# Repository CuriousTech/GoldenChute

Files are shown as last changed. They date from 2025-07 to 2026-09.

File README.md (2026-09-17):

# GoldenChute
GoldenMate UPS monitor and Windows shutdown software  
  
This is a simple modification for the GoldeMate UPS to access the information displayed as well as safely shut a Windows PC down before the battery runs down. One of the most important features of a UPS.  
  
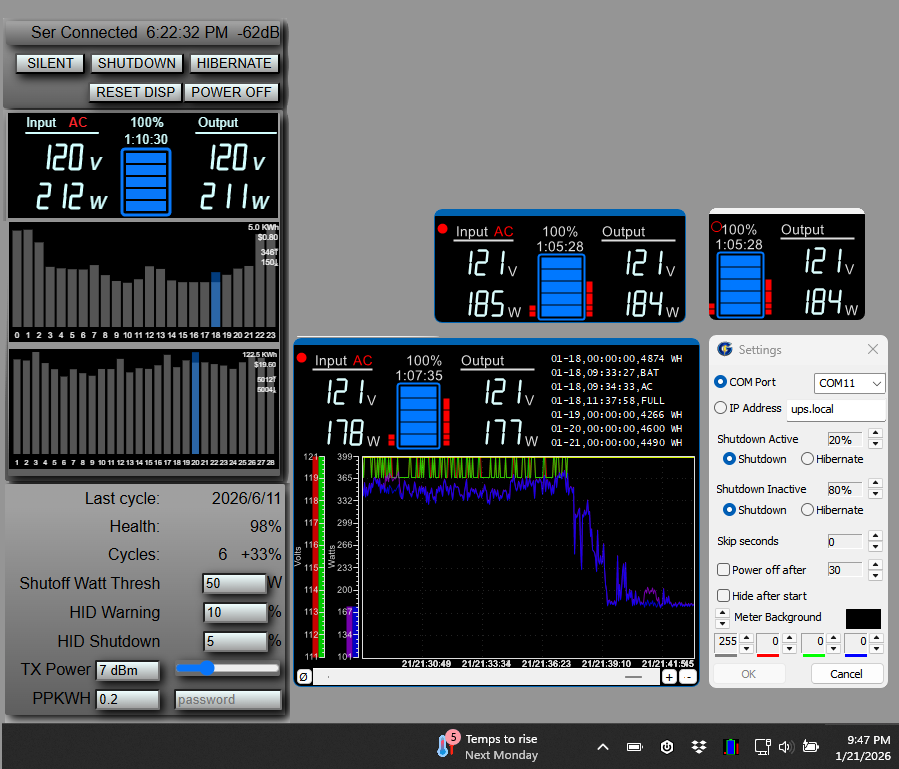
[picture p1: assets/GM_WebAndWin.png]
WebAndWinPic
  
  
The left is the web page for remote access. The other windows are the Windows app (different sizes).  
  
This mod requires opening the case of the UPS and plugging in a small board inline with the front display. It's a segmented display with SPI interface, so the ESP32 decodes all the segment bits and translates them to something usable. The data is only sent to the display for 60 seconds when the power button is short-pressed, so this also simulates the button (in parallel). The 5V power for the ESP32 needs to be external since the display 5V is only on when the display is powered, and may not support the current requirement, so run a USB cable to the rear panel and cut a small notch so the case can slide back on, and connect to PC or USB power supply (powered by the UPS, so it's powered on battery).  

Note: The interface could easily be changed to any small Arduino or microcontroller, since it only connects to 3 pins for data (no ground) and momentarily shorts the power button (28V or 56V pulled low).  
  
I beleve the first model had a push-on/push-off button and the display stayed on. For that model, all you need is the PCB, ESP32, and 7 pin connectors. Leave out the solid state relay, R2 and 2 pin connectors.  
  
**Parts needed:**  
-  [PCB r4](https://oshpark.com/shared_projects/ARcXjJj3)  Moved the DI trace to fix RF issues with a new module, and removed ground fill around it as well.  
-  [ESP32-C3-super mini](https://www.aliexpress.us/item/3256807353297685.html), or [ESP32-S3-super mini](https://www.aliexpress.us/item/3256809251035142.html) for USB-HID support (native Windows, NUT, etc.)  
-  AQY282S (SSR)  I used this one because it's cheap and currently well stocked.  
-  R1 470 ohm 0805 resistor  
-  M & F [JST-XH](https://www.aliexpress.us/item/3256807274583113.html) (This one has wires to place it closer to the side for better signal) 7P 2.54mm, or 7P 0.1" pinheader  
-  2P 2.54mm/0.1" connector M  
-  2P 2.54mm/0.1" connector F + 2 wires (3-4 inches) Note: The button is non-polarized (The AliExpress above didn't fit the 2 pin) Dupont will work if nothing else.  
-  1x 18650 cell and [holder](https://www.aliexpress.us/item/3256808726723157.html) for battery power on the ESP32. Solder the wires on the back of the ESP32 first.  
-  r5 board: 3x BSS138 (MOSFET), 3x 10K resistors, and another AQY282S + 470 resistor. This is still an untested board. The addition of the SSR is because the front button is DPST. One side is for the BMS (display control). The other side is for the UPS (powering on/off and beeper mute). Some models have separate buttons for this function, and may have different input timings.  
  
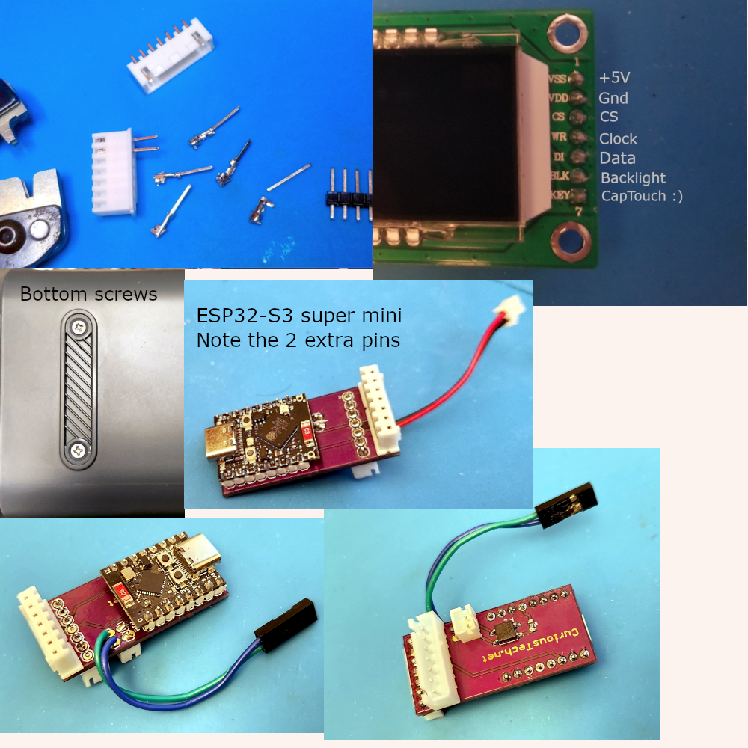
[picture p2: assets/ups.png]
UPS Board
  
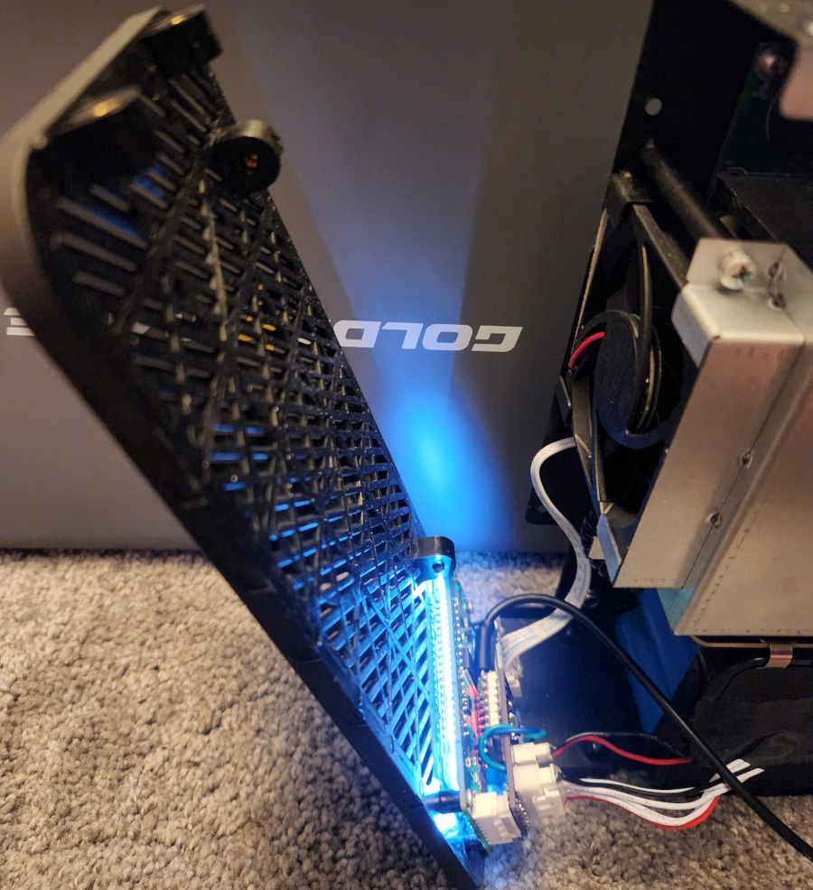
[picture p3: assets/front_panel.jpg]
Front panel
  
  
Remove the 2 screws under each rubber foot. Slide the cover off (to the front).  Remove the 6 screws around the front panel.  
  
The female XHB (XH works well, and a plain female pinheader actually holds well if you can't find XH/B) connector needs pins or wire lead clippings crimped to make it solder to a PCB. I used male pinheader pins. Install the 2-pin connector and wires before the ESP32 for ease.  
  
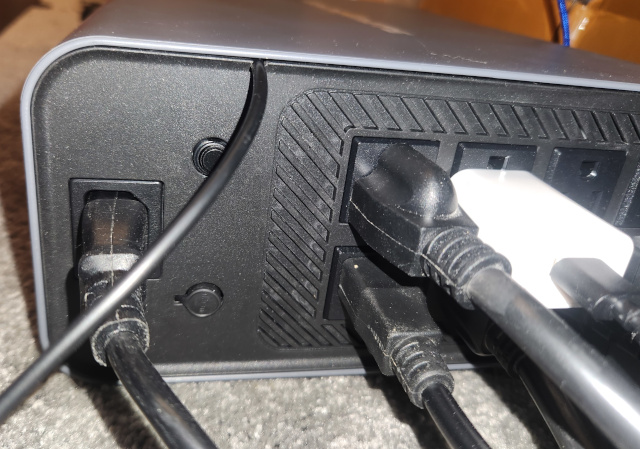
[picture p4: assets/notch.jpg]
Back
  
Cut a notch in the rear panel to fit the USB cable.  
  
**Arduino:**  
Settings for router SSID and SSID password are in Config.h, as well as the remote password for web control. If they aren't set or the SSID changes, EspTouch can be used.  
Compiling the code should be easy. Most information is in UPS.ino, like where to get the libraries needed, and settings for the ESP32-C3-super mini such as enabling CDC on boot (for serial output).  
There's code in UPS.ino to setup the initialDate, lastCycleDate, Cycles and percent to be used once, and commented out if desired.  

The ESP32-S3 super mini is mostly pin compatible, and has HID support for UPS emulation. It has 2 more pins (1 per side) that just overhang on the PCB. The current GPIO pins in the code for the C3 are incorrect for the r3 board. Just 1 pin is different. There are likely different models of the S3 also. Just make sure GND is pin 2.  
  
**Web page:**  
The HIBERNATE and SHUTDOWN buttons send a message to the Goldenmate app to start the shutdown or hibernate process.  
The POWER OFF button will hold the power button for 5 seconds to shut the UPS off. This will cut power to everything, including the ESP32 most likely.  
RESET DISP causes a timeout in the display restart timer. When the USP returns to AC power, once in a while the display malfunctions, but the data is still good. This just fixes it.  
BEEPING / SILENT toggles to enable a button tap at the start of backup power, disabling the beeps.  
Shutoff Watt Threshold prevents the delayed shutoff from operating until the watts out drops below the set value.  
HID Warn % is what Windows uses to pop up a warning.  
HID shutdown % is what Windows uses to shutdown when the battery level reaches that value. Set the warning above the shutdown. These are overridden by settings in Windows, though, so probably not useful.  
PPKWH (price per killowatt hour) is used for, well, calcuating cost.  
password needs to be the same as what's in Config.h and needs to be set to allow any input (button presses or value changes). You can leave it blank any other time.  
  
**Windows app:**  
Extract the exe and move it to somewhere like C:\Goldenmate.  The startup folder symbolic link will auto-generate to this path.  
Clicking on the top-right corner of the app will hide it.  
Right-click for context menu (settings, quit, clear log/chart)  
The outage and daily WH log (top right area, hidden when small) is blank until an entry is created.  Entries are comma delimited lines saved in a file in the local exe folder, named ups_log.txt (or ups_log1.txt for the 2nd instance...).  
  
**Settings:**  
Right-click in the window, or go to the tray, and right click the icon for the menu. Select "Settings" and enter the IP address of the ESP32 device in the format "192.168.xxx.xxx" which you can find in the Arduino IDE ports, named UPS (192.168.xxx.xxx). Up to 8 clients can be connected at once. Your router should also be on UPS when using this method.  
If it connects, there should be a small red circle in the top left of the app. This will blink when data is received. Serial is the same.  
COM Port (Note: using serial will cause the ESP32 to reset every time the app exits or another app accesses the COM port, which loses WH history and may get off track if charging).  
The radio buttons allow selecting either COM or websocket.  
 Note: When using HID, the Windows app will not be able to use serial, but can connect to the IP address. There's no resetting, which is better, but be careful of the HID shutdown % along with the app shutdown %. The app should be set higher, and HID can be fallback if it's not running for any reason.  
Percent to shut down: Active (red bars left of battery in the main display and tray icon) and Inactive (right red bars) depends on whether the monitor is in standby. The depth of discharge (D.O.D.) determines the impact on health. When inactive, it should shut down at 70% for best health. When active, more time can be allowed for manual shutdown. The % is just the bar levels, not actual percent (which could possibly be inaccurate). There is a 10 second delay when it reaches the desired %, then it will shut down or hibernate/hibrid-sleep if that is set up properly and doesn't fail, otherwise it will shut down.  
Note: Hibrid-sleep can wake immediately by odd USB devices if not set up properly. It should be tested before use. It will also slowly drain the battery over time.  
Skip seconds: 0 will add data to the chart every second (total 24 hours). 1 would be 48 hours, but records peak values of 2 seconds.  
Alerts cause the window to popup and show a text box such as "Serial timeout/in use" or WebSocket disconnected" with annoying sound.  
Power off after [30] seconds: Will turn the UPS power off (cutting power to everything on it) the delayed time (15 secs to 60 mins) after the PC begins shutdown/hibernate, and also waits for the watts out to drop below the shutoff watt threshold setting on the webpage.  
 Note:The ESP will also lose power, so there's no way to remotely power it back on.  
Hide after start causes the window to hide 4 seconds after startup.

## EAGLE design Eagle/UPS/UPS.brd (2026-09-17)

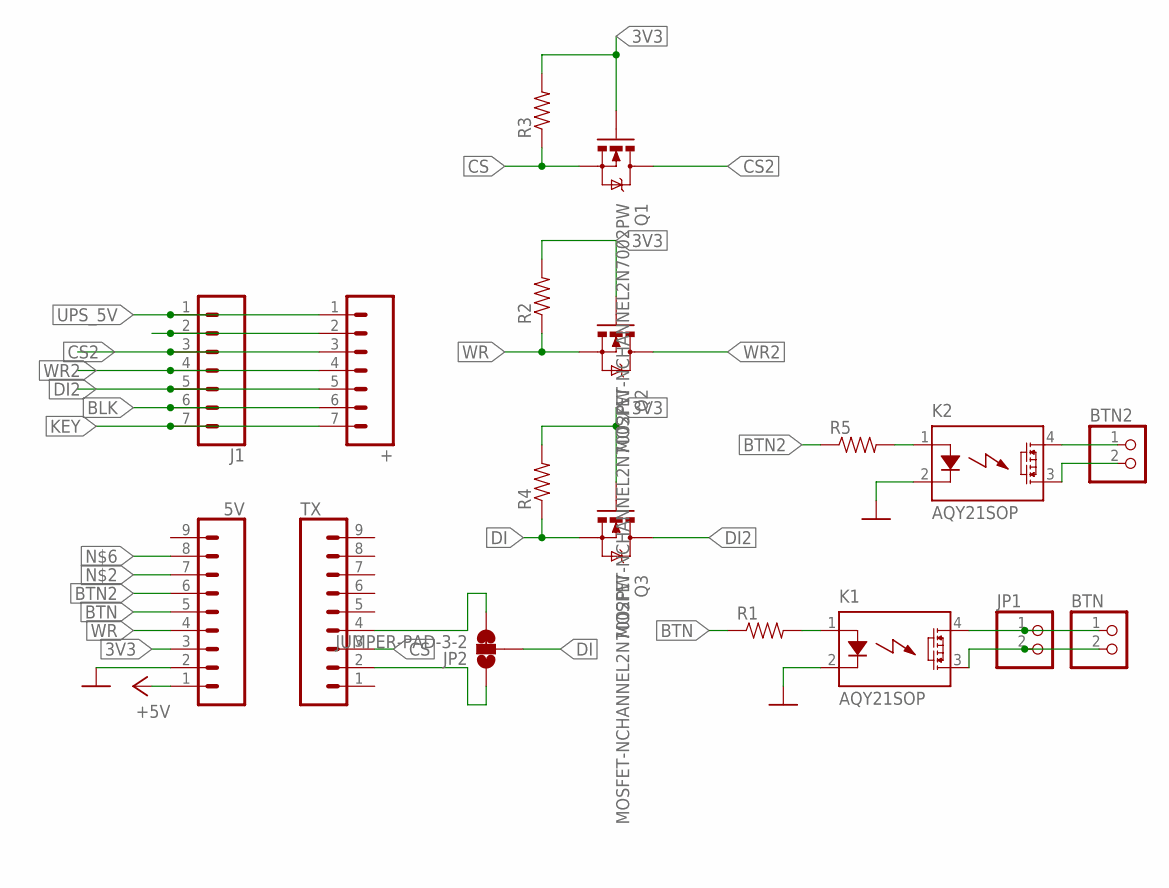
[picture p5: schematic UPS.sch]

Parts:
5V: CONN_09; 1X09
+: CONN_07; 1X07
BTN, BTN2: PINHD-1X2; 1X02
J1: CONN_07; 1X07
JP1: PINHD-1X2; 1X02
JP2: JUMPER-PAD-3-2; PAD-JUMPER-3-2OF3_NC_BY_TRACE_YES_SILK_FULL_BOX
K1, K2: AQY21SOP; SOP04
Q1, Q2, Q3: MOSFET-NCHANNEL2N7002PW; SOT323
R1, R2, R3, R4, R5: RESISTOR0805-RES; 0805
TX: CONN_09; 1X09

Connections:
3V3: 5V.3, Q1.1 (G), Q2.1 (G), Q3.1 (G), R2.2, R3.2, R4.2
+5V: 5V.1
BLK: +.6, J1.6
BTN: 5V.5, R1.1
BTN2: 5V.6, R5.1
CS: Q1.2 (S), R3.1, TX.3
CS2: +.3, J1.3, Q1.3 (D)
DI: JP2.2, Q3.2 (S), R4.1
DI2: +.5, J1.5, Q3.3 (D)
GND: 5V.2, K1.2 (K), K2.2 (K)
KEY: +.7, J1.7
unnamed: BTN.1, JP1.1, K1.4 (DS1)
unnamed: BTN.2, JP1.2, K1.3 (DS2)
unnamed: K1.1 (A), R1.2
unnamed: JP2.3, TX.4
unnamed: JP2.1, TX.2
unnamed: BTN2.1, K2.4 (DS1)
unnamed: BTN2.2, K2.3 (DS2)
unnamed: K2.1 (A), R5.2
UPSGND: +.2, J1.2
UPS_5V: +.1, J1.1
WR: 5V.4, Q2.2 (S), R2.1
WR2: +.4, J1.4, Q2.3 (D)

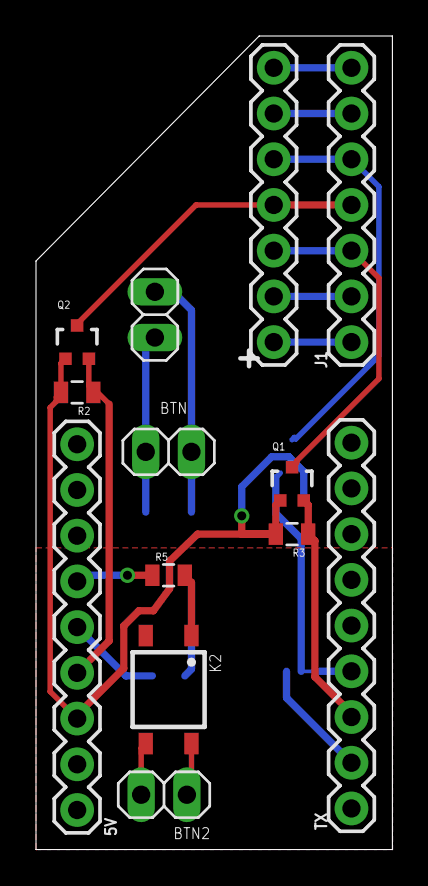
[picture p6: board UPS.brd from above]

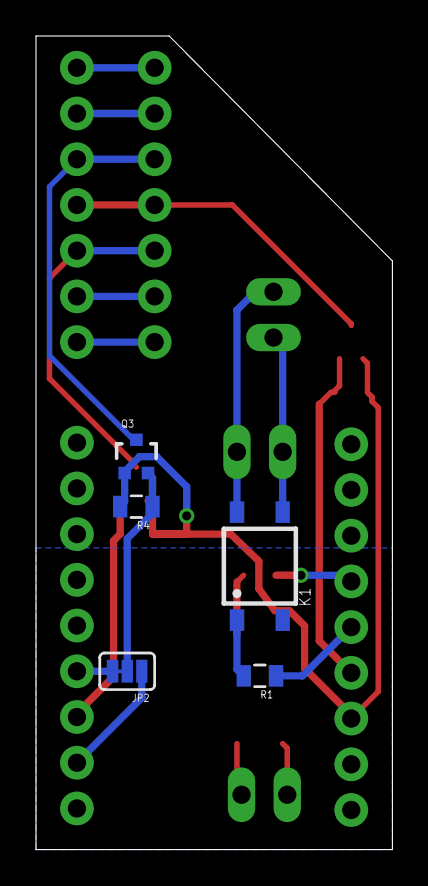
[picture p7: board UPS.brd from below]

Board: 2 copper layers, 19.8 x 45.2 mm, 18 parts (5 on the bottom side), 22 nets.

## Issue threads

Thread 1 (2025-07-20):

Connection issues

AlecMcCutcheon, 2025-07-20:
Plugged in the UPS over USB but not seeing an COM ports in the GUI and no data showing in the GUI

Any luck on the NUT driver.

CuriousTech, 2025-07-25:
The USB port will be the same as what you see in the Arduino IDE when programming the ESP-32-C3.

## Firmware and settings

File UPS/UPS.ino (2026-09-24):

/**The MIT License (MIT)

Copyright (c) 2025 by Greg Cunningham, CuriousTech

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
THE SOFTWARE IS PROVIDED "AS IS", WITHOUT WARRANTY OF ANY KIND, EXPRESS OR
IMPLIED, INCLUDING BUT NOT LIMITED TO THE WARRANTIES OF MERCHANTABILITY,
FITNESS FOR A PARTICULAR PURPOSE AND NONINFRINGEMENT. IN NO EVENT SHALL THE
AUTHORS OR COPYRIGHT HOLDERS BE LIABLE FOR ANY CLAIM, DAMAGES OR OTHER
LIABILITY, WHETHER IN AN ACTION OF CONTRACT, TORT OR OTHERWISE, ARISING FROM,
OUT OF OR IN CONNECTION WITH THE SOFTWARE OR THE USE OR OTHER DEALINGS IN THE
SOFTWARE.
*/

// Goldenmate UPS with ESP32-C3-super mini or ESP32-S3-super mini

// Build with Arduino IDE 1.8.19, ESP32 2.0.14 or 3.2.0-3.3.7
// CPU Speed: 80MHz(C3) 80MHz(S3) (Warning: These both seem to burn up at the highest clock speed)
// USB CDC On Boot: Enabled - for serial output over USB, HID doesn't matter
// Partition: Default 4MB with spiffs

///////////////////////////////////////////////////
//  Model       Volts Amps    Wh      ~98% integer
// 1000VA/600W  25.6V 6Ah   = 153.6Wh 150
// 1000VA/800W  25.6V 9Ah   = 230.4Wh 226
// 1500VA/1000W 51.2V 5.8Ah= 296Wh    291 (note: 1500 & 2000 models have a USB-HID type output AFAIK)
// 1500VA/1200W 51.2V 6Ah  = 307Wh    301   (manual is incorrect, so I'm guessing)
// 2000VA/1600W 51.2V 9Ah  = 460.8Wh  451
#define BATTERY_WH 226

#define TZ  "EST5EDT,M3.2.0,M11.1.0"  // https://github.com/nayarsystems/posix_tz_db/blob/master/zones.csv

#include <WiFi.h>
#include <ESPAsyncWebServer.h> // https://github.com/ESP32Async/ESPAsyncWebServer (3.10.1) and AsyncTCP (3.4.10)
#include <time.h>
#include <JsonParse.h> //https://github.com/CuriousTech/ESP-HVAC/tree/master/Libraries/JsonParse
#include <ArduinoOTA.h>
#include <ESPmDNS.h>
#include "Config.h"
#include "pages.h"
#include "jsonstring.h"

// ESP32-C3 on r2 PCB
#if CONFIG_IDF_TARGET_ESP32C3
#define CS_PIN  GPIO_NUM_7
#define DIN_PIN GPIO_NUM_6 // GPIO_NUM_8 // PCB r3
#define SCK_PIN GPIO_NUM_4
#define LED     8
#define BMS_BTN 3
#define UPS_BTN 2
// ESP32-S3 on r3 PCB
#elif CONFIG_IDF_TARGET_ESP32S3
#define CS_PIN  GPIO_NUM_1
#define DIN_PIN GPIO_NUM_2
#define SCK_PIN GPIO_NUM_13
#define LED     48
#define BMS_BTN 12
#define UPS_BTN 11
//#define USE_HID 1  // Uncomment for HID device
// ESP32-C6
#elif CONFIG_IDF_TARGET_ESP32C6
#define CS_PIN  GPIO_NUM_7
#define DIN_PIN GPIO_NUM_6 // GPIO_NUM_8 // PCB r3
#define SCK_PIN GPIO_NUM_4
#define LED     8
#define BMS_BTN 3
#define UPS_BTN 2
#else
static_assert(FALSE, "Set pins for new device");
#endif

// Auto-enabled when building for ESP32-S3 and uses HID
#if CONFIG_TINYUSB_HID_ENABLED && USE_HID
#include "HIDPowerDev.h"
HIDPowerDevice Device;
#endif

bool bKeyGood;
IPAddress lastIP;
int nWrongPass;
uint8_t nOnBattCount;
int8_t nWsConnected;

// The battery levels for each bar and blinking bar
const byte battLevels[] = { 5, 10, 20, 40, 60, 80, 90, 100 };

AsyncWebServer server( 80 );
AsyncWebSocket ws("/ws"); // access at ws://[esp ip]/ws
AsyncWebSocket wsb("/bin"); // binary websocket for Windows app
//AsyncWebSocket wsb2("/other"); // Add some other WebSocket for alternate needs. Duplicate the wsb references for your format

const int8_t powerLevels[] = {
    WIFI_POWER_MINUS_1dBm,
    WIFI_POWER_2dBm,
    WIFI_POWER_5dBm,
    WIFI_POWER_7dBm,
    WIFI_POWER_8_5dBm,
    WIFI_POWER_11dBm,
    WIFI_POWER_13dBm,
    WIFI_POWER_15dBm,
    WIFI_POWER_17dBm,
    WIFI_POWER_18_5dBm,
    WIFI_POWER_19dBm,
    WIFI_POWER_19_5dBm, // 11
};

uint32_t WsClientID;
uint32_t binClientCnt;
tm lTime;

void jsonCallback(int16_t iName, int iValue, char *psValue);
JsonParse jsonParse(jsonCallback);

Config cfg;

bool bConfigDone; // EspTouch config
bool bStarted; // WiFi started
bool bRequestSD = false; // request PC shutdown
uint32_t nLongPress = 0; // Long press the power button
bool bPushBMS_SSR = false;
bool bPushUPS_SSR = false;

bool bGMFormatSerial;
uint32_t spiMS = 10000000;
bool bNeedRestart; // display may need fix after switching from battery to AC
uint16_t nShutoffDelay;

// percent calculator
uint8_t nLevelPercent;
uint8_t nBarPercent;
uint32_t nWattsAccum;
uint32_t nWattsPerBar;
uint8_t nDrainStartPercent;
uint32_t nSecondsRemaining;

uint32_t nWattsAccumHr;
uint16_t nWhCnt;
uint16_t nWattMin[24], nWattMax[24];

struct flagBits{
  uint16_t OnUPS : 1;
  uint16_t OnAC : 1;
  uint16_t error : 1; // WattsIn will be error #
  uint16_t charging : 1;
  uint16_t noData : 1; // display timeout indicator
  uint16_t battLevel : 3; // 0-7 (used by the app for shutdown)
  uint16_t battDisplay : 5; // Raw bits 0=top 4=bottom (0 and 4 blink)
  uint16_t needCycle : 1; // if it's been over 90 days with no 100% cycle
  uint16_t shuttingOff : 1; // shutoff timer is running
  uint16_t powered : 1; // UPS is powered on
};

struct upsData
{
  uint8_t  head[2];  // should be 16 bit aligned
  flagBits b;
  uint8_t  VoltsIn;
  uint8_t  VoltsOut;
  uint16_t WattsIn;  // AC=UPS+outputs, Batt=pre-inverter, error=error #
  uint16_t WattsOut; // AC=just output, Batt=post-inverter (out-in=efficiency)
  uint16_t Capacity;  // Battery capacity in Wh
  uint8_t  battPercent;
  uint8_t  Health;
  uint8_t  reserved;
  uint8_t  sum;
}; // 16 bytes

upsData binPayload;

struct upsHourlyWh
{
  uint32_t head;
  uint32_t now;
  uint16_t arr[24];
};

upsHourlyWh hourlyWh;

// cccaaaaaadddd
struct holtekBits{
  uint16_t data : 4;
  uint16_t addr : 6;
  uint16_t cmd : 3;
};

union holtek{
    uint16_t w;
    holtekBits h;
};

// ISR working mem
volatile holtek hx;
volatile uint8_t ups_nibble[32]; // valid is 0-29, but the addr could hit 31, so be safe
volatile bool bReady;

bool decodeSegments(upsData& udata);
void calcPercent(void);
void checkSerial(void);
uint8_t battHealth(void);
void calcMinMax(void);
void usageAdd(void);

String dataJson()
{
  jsonString js("state");

  js.Var("t", (uint32_t)time(nullptr));
  js.Var("rssi", WiFi.RSSI() );
  js.Var("connected", binClientCnt);
  js.Var("sercon", bGMFormatSerial);  // (bGMFormatSerial || otherMonitor)
  js.Var("nodata", binPayload.b.noData);
  js.Var("ppkwh", cfg.ppkw);
  if(nWhCnt)
    js.Var("wh", nWattsAccumHr / nWhCnt); // usage this hour in Wh
  js.Array("wattArr", hourlyWh.arr, 24);
  js.Array("wmin", nWattMin, 24);
  js.Array("wmax", nWattMax, 24);
  uint8_t nPerc = cfg.nPercentUsage;
  if(binPayload.b.OnUPS) // add the live percent used
    nPerc += nDrainStartPercent - binPayload.battPercent;
  js.Var("percuse", nPerc);
  js.Var("cycles", cfg.nCycles);
  js.Var("initdate", cfg.initialDate);
  js.Var("cycledate", cfg.lastCycleDate);
  js.Var("health", battHealth());
  js.Var("nc", binPayload.b.needCycle);
  js.Var("wcl", cfg.WarnCapLimit);
  js.Var("rcl", cfg.RemainCapLimit);
  js.Var("swt", cfg.ShutoffWattThresh);
  js.Var("pwr", cfg.powerLevel);
  js.Var("nobeep", cfg.bNoBeep);
  js.Array("daily", cfg.nDailyWh, 31);
#if (CONFIG_TINYUSB_HID_ENABLED && USE_HID)
  js.Var("HID", 1);
#else
  js.Var("HID", 0);
#endif
  return js.Close();
}

String statusJson()
{
  jsonString js("data");
  js.Var("t", (uint32_t)time(nullptr));
  js.Var("rssi", WiFi.RSSI());
  js.Var("connected", binClientCnt);
  js.Var("sercon", bGMFormatSerial);
  js.Var("AC", binPayload.b.OnAC);
  js.Var("UPS", binPayload.b.OnUPS);
  js.Var("voltsIn", binPayload.VoltsIn);
  js.Var("wattsIn", binPayload.WattsIn);
  js.Var("voltsOut", binPayload.VoltsOut);
  js.Var("wattsOut", binPayload.WattsOut);
  js.Var("BATT", binPayload.b.battDisplay);
  js.Var("LVL", binPayload.b.battLevel);
  js.Var("battPercent", binPayload.battPercent );
  js.Var("error", binPayload.b.error);
  js.Var("nodata", binPayload.b.noData);
  js.Var("secsrem", nSecondsRemaining);
  js.Var("so", nShutoffDelay);
  js.Var("pwrd", binPayload.b.powered);
  return js.Close();
}

const char *jsonList1[] = {
  "key",
  "hibernate",
  "shutdown",
  "restart",
  "ppkwh",
  "power",
  "wcl",
  "rcl",
  "swt",
  "plvl",
  "bump", // 10
  "nobeep",
  NULL
};

void parseParams(AsyncWebServerRequest *request)
{
  if (nWrongPass && request->client()->remoteIP() != lastIP) // if different IP drop it down
    nWrongPass = 10;

  lastIP = request->client()->remoteIP();

  for ( uint8_t i = 0; i < request->params(); i++ )
  {
    const AsyncWebParameter* p = request->getParam(i);
    String s = request->urlDecode(p->value());

    for(uint8_t idx = 0; jsonList1[idx]; idx++)
      if( p->name().equals(jsonList1[idx]) )
      {
        int iValue = s.toInt();
        if(s == "true") iValue = 1;
        jsonCallback(idx, iValue, (char *)s.c_str());
        break;
      }
  }
}

void jsonCallback(int16_t iName, int iValue, char *psValue)
{
  if (!bKeyGood && iName)
  {
    if (nWrongPass == 0)
      nWrongPass = 10;
    else if ((nWrongPass & 0xFFFFF000) == 0 ) // time doubles for every high speed wrong password attempt.  Max 1 hour
      nWrongPass <<= 1;
    return; // only allow for key
  }

  switch(iName)
  {
    case 0: // key
      if (!strcmp(psValue, cfg.szPassword)) // first item must be key
        bKeyGood = true;
      break;
    case 1: // hibernate
      {
        static char data[] = "HIBR";
        wsb.binaryAll(data, 4);
#if !(CONFIG_TINYUSB_HID_ENABLED && USE_HID)
        static uint8_t data2[] = {0xAB, 'H','I','B','R'};
        Serial.write(data2, 5);
#endif
      }
      break;
    case 2: // shutdown
      {
        static char data[] = "SHDN";
        wsb.binaryAll(data, 4);
#if CONFIG_TINYUSB_HID_ENABLED && USE_HID
        bRequestSD = true;
#else
        static uint8_t data2[] = {0xAB, 'S','H','D','N'};
        Serial.write(data2, 5);
#endif
      }
      break;
    case 3: // restart
      bNeedRestart = true;
      break;
    case 4: // ppkwh
      cfg.ppkw = iValue;
      break;
    case 5: // power (0xABC20000 can be used to power on or cancel power off)
      nShutoffDelay = nLongPress & 0xFFFF;
      if(nShutoffDelay == 0 && binPayload.b.powered)
         nLongPress = 0; // cancel
      else
         nLongPress = iValue >> 16; // random num to make it safer
      break;
    case 6: // wcl
      cfg.WarnCapLimit = constrain(iValue, 5, 90);
#if CONFIG_TINYUSB_HID_ENABLED && USE_HID
      Device.setCapLimits(cfg.RemainCapLimit, cfg.WarnCapLimit);
#endif
      break;
    case 7: // rcl
      cfg.RemainCapLimit = constrain(iValue, 5, 80);
#if CONFIG_TINYUSB_HID_ENABLED && USE_HID
      Device.setCapLimits(cfg.RemainCapLimit, cfg.WarnCapLimit);
#endif
      break;
    case 8: // swt
      cfg.ShutoffWattThresh = iValue;
      break;
    case 9: // plvl
      cfg.powerLevel = constrain(iValue, 0, sizeof(powerLevels) - 1);
      WiFi.setTxPower((wifi_power_t)powerLevels[cfg.powerLevel]);
      break;
    case 10: // bump
      cfg.nPercentUsage += iValue;
      break;
    case 11:
      cfg.bNoBeep = (iValue) ? true:false;
      break;
  }
}

void sendState()
{
  if(nWsConnected)
    ws.textAll(dataJson());
}

void onWsEvent(AsyncWebSocket * server, AsyncWebSocketClient * client, AwsEventType type, void * arg, uint8_t *data, size_t len)
{  //Handle WebSocket event

  switch(type)
  {
    case WS_EVT_CONNECT:      //client connected
      client->keepAlivePeriod(50);
      client->text( statusJson() );
      client->text( dataJson() );
      nWsConnected++;
      break;
    case WS_EVT_DISCONNECT:    //client disconnected
      if(nWsConnected)
        nWsConnected--;
      break;
    case WS_EVT_ERROR:    //error was received from the other end
      break;
    case WS_EVT_PONG:    //pong message was received (in response to a ping request maybe)
      break;
    case WS_EVT_DATA:  //data packet
      AwsFrameInfo * info = (AwsFrameInfo*)arg;
      if(info->final && info->index == 0 && info->len == len){
        //the whole message is in a single frame and we got all of it's data
        if(info->opcode == WS_TEXT){
          data[len] = 0;
          uint32_t ip = client->remoteIP();
          WsClientID = client->id();
          jsonParse.process((char *)data);
        }
      }
      break;
  }
}

void onBinEvent(AsyncWebSocket * server, AsyncWebSocketClient * client, AwsEventType type, void * arg, uint8_t *data, size_t len)
{  //Handle binary WebSocket event (/bin)

  switch(type)
  {
    case WS_EVT_CONNECT:      //client connected
      client->keepAlivePeriod(50);
      binClientCnt++;
      client->binary((uint8_t*)&binPayload, sizeof(binPayload));
      nShutoffDelay = 0; // cancel shut down if there is one
      nLongPress = 0;
      break;
    case WS_EVT_DISCONNECT:    //client disconnected
      if(binClientCnt)
        binClientCnt--;
      break;
    case WS_EVT_ERROR:    //error was received from the other end
      break;
    case WS_EVT_PONG:    //pong message was received (in response to a ping request maybe)
      break;
    case WS_EVT_DATA:  //data packet
      AwsFrameInfo * info = (AwsFrameInfo*)arg;
      if(info->final && info->index == 0 && info->len == len){
        switch(data[0])
        {
          case 'W': // send wh array
            {
              hourlyWh.head = 0x00DEBCAA;
              hourlyWh.now = nWattsAccumHr / 3621; // current this hour
              client->binary((uint8_t*)&hourlyWh, sizeof(hourlyWh));
            }
            break;
          case 'D':
            {
              uint32_t binData[33];
              binData[0] = 0x00DEBCAB;
              binData[1] = cfg.ppkw;
              memcpy( (uint8_t*)&binData[2], &cfg.nDailyWh, sizeof(cfg.nDailyWh)); // full month data
              client->binary((uint8_t*)&binData, sizeof(binData));
            }
            break;
          case 0xAB: // shutoff delay
            if(data[1] == 0xC2)
            {
              nShutoffDelay = (data[2] << 8) | data[3];
              if(nShutoffDelay == 0) // cancel poweroff
                nLongPress = 0;
              else
                nLongPress = (data[0] << 8) || data[1];
            }
            usageAdd(); // save usage before shutdown (app sends a delay time or 0 if not used)
            cfg.update();
            break;
        }
      }
      break;
  }
}

void alert(String txt)
{
  jsonString js("alert");
  js.Var("text", txt);
  ws.textAll(js.Close());
}

static void CLK_ISR(void *arg)
{
  hx.w <<= 1UL; // shift the bits in
  hx.w |= digitalRead(DIN_PIN);
}

static void CS_ISR(void *arg) // CS raises after 13th bit
{
  if(hx.h.cmd != 5) // write to address
  {
    hx.w = 0; // clear if different command or display is off (high-Z state)
    return;
  }
  if(hx.h.addr & 0x20) // block addr over 31
  {
    hx.w = 0;
    return;
  }

  ups_nibble[hx.h.addr] = hx.h.data;
  if(hx.h.addr == 28 || hx.h.addr == 29) // last value complete (added a 1ms delay in case 28 hits, usually does)
    bReady = true;
  hx.w = 0; // clear just in case
}

// Do a simple checksum and set the head value
void checksumData()
{
  binPayload.head[0] = 0xAB;
  binPayload.head[1] = 0xCD;

  uint8_t *pData = (uint8_t *)&binPayload + 2;
  uint8_t sum = 0;
  for(uint8_t i = 0; i < sizeof(upsData) - 3; i++)
    sum += pData[i];
  binPayload.sum = sum;
}
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
void loop()
{
  static uint8_t hour_save, sec_save;
  static uint32_t sentMS;
  static uint32_t lastMSbtn;
  static uint32_t lastMSbtn2;
  static uint32_t lastMS1sec;

  ArduinoOTA.handle();

  // BMS button press simulator
  if(lastMSbtn)
  {
    if(millis() - lastMSbtn > 500)
    {
      digitalWrite(BMS_BTN, LOW); // release button after 500ms
      lastMSbtn = 0;
    }
  }
  if(bPushBMS_SSR) // press button, start ms timer
  {
    bPushBMS_SSR = false;
    digitalWrite(BMS_BTN, HIGH);
    lastMSbtn = millis();
  }

  // UPS button press simulator
  if(lastMSbtn2)
  {
    uint32_t ms = (nLongPress == 0xABC2) ? 5100:500;
    if(millis() - lastMSbtn2 > ms)
    {
      digitalWrite(UPS_BTN, LOW); // release button after 500ms (or 5.1 seconds for shutoff)
      if(nLongPress) binPayload.b.powered = !binPayload.b.powered;
      nLongPress = 0;
      lastMSbtn2 = 0;
    }
  }
  if(bPushUPS_SSR) // press button, start ms timer
  {
    bPushUPS_SSR = false;
    digitalWrite(UPS_BTN, HIGH);
    lastMSbtn2 = millis();
    if(nLongPress && binPayload.b.powered)
    {
      usageAdd(); // add up in case it's powered off
      cfg.update(); // save data before power off
    }
  }


  // Last UPS LCD segment bits captured
  if(bReady)
  {
    delay(1); // wait for 2nd hit
    bReady = false;
    spiMS = millis(); // time between each frame is ~980ms including the 14ms of 30 values
    if( decodeSegments(binPayload) )
    {
      sentMS = millis();
      calcPercent();
      calcTimeRemaining();
      calcMinMax();
/*
      if(!binPayload.b.powered && binPayload.b.OnUPS == 0) // power returned
      {
        nLongPress = 0xABC2;
        bPushUPS_SSR = true;
      }
*/  
      binPayload.b.powered = 1;

      binPayload.b.shuttingOff = (nLongPress && binPayload.b.powered) ? 1:0;

      checksumData(); // prepare it for transmit

      ws.textAll( statusJson() ); // send to web page or other websocket clients

      if(binClientCnt) // send to Windows Goldenchute client(s) over WiFi
      {
        wsb.binaryAll((uint8_t*)&binPayload, sizeof(binPayload));
      }

#if CONFIG_TINYUSB_HID_ENABLED && USE_HID
      PresentStatus ps;

      ps.w = 0;
  
      // just in case it's not installed properly
      uint8_t percent = (binPayload.b.noData) ? 100 : binPayload.battPercent;
  
      ps.b.Charging = binPayload.b.charging;
      ps.b.ACPresent = binPayload.b.OnAC;
      ps.b.Discharging = binPayload.b.OnUPS;
      ps.b.BatteryPresent = 1;
      ps.b.FullyCharged = (binPayload.b.charging == 0 && binPayload.b.OnAC == 1);
      ps.b.BelowRemainingCapacityLimit = (percent <= cfg.RemainCapLimit);
      ps.b.ShutdownImminent = (percent <= 2 || nLongPress);
      ps.b.CommunicationLost = binPayload.b.noData;
      ps.b.ShutdownRequested = bRequestSD;
      bRequestSD = false;
      Device.SetPresentStatus(ps.w, percent, binPayload.VoltsOut);
#else
      if(bGMFormatSerial)
      {
        Serial.write((uint8_t*)&binPayload, sizeof(binPayload) );
      }
      else if(binPayload.b.error)
      {
        String s = "ERROR ";
        s += binPayload.WattsIn; // Send error code text
        Serial.println(s);
      }
      else
      {
        // default: text "0,250,100" for not on battery, 250 watts, battery level 100%
        // or make your own format, or emulate another UPS
        String s = "";
        s += (binPayload.b.OnUPS) ? 1:0;
        s += ",";
        s += binPayload.WattsOut;
        s += ",";
        s += binPayload.battPercent;
        Serial.println(s);
      }
#endif
    }
  }

  if(millis() - lastMS1sec >= 1000 && lastMSbtn == 0) // only do stuff once per second and not while button is being pressed
  {
    lastMS1sec = millis();
    getLocalTime(&lTime); // used globally (!first call can block for several seconds)

    if(binPayload.b.OnUPS && nSecondsRemaining) // make it count down
      nSecondsRemaining--;

    static uint8_t nSSRsecs = 1;
    static bool bRestartingDisplay = false;

    static uint8_t wattArr[4] = {255, 255, 255, 255};
    static uint8_t waIdx = 0;

    wattArr[waIdx] = binPayload.WattsOut;
    waIdx++;
    waIdx &= 3;

    if(nLongPress == 0xABC2 && nShutoffDelay)
    {
      if(--nShutoffDelay == 0) // Shutoff delay from PC or web
      {
        if( binPayload.b.OnUPS == 0) // Power has resumed (assuming it will continue)
        {
          nShutoffDelay = 0;
          nLongPress = 0;
        }
        else if(nLongPress == 0xABC2 && wattArr[0] < cfg.ShutoffWattThresh && wattArr[1] < cfg.ShutoffWattThresh && wattArr[2] < cfg.ShutoffWattThresh && wattArr[3] < cfg.ShutoffWattThresh)
        {
          nShutoffDelay = 5; // bump back up to 5 seconds, and time down again until it's low enough
        }
        else
        {
          bPushBMS_SSR = true;
        }
      }
    }

    // Fix for display going wonky after returning to AC power
    if(binPayload.b.OnUPS == 0)
    {
      if( bNeedRestart )
      {
        bNeedRestart = false;
        bRestartingDisplay = true; // ignore upcoming SPI timeout
        nSSRsecs = 65; // Set to higher than display timeout
      }

      if( bRestartingDisplay && millis() - spiMS > 1200) // catch the poweroff
      {
        nSSRsecs = 1; // and ready to turn back on
      }
    }
    else // On battery - if nobeep option, tap the button just after start
    {
      if(nOnBattCount < 10)
        nOnBattCount++;
      if(cfg.bNoBeep)
      {
        if(nOnBattCount == 3)
        {
           bPushUPS_SSR = true;
           nLongPress = 0;
        }
      }
    }

    // simulate button press every ~60s or less (anything under will reset the timeout)
    if(--nSSRsecs == 0)
    {
      if(binPayload.b.OnUPS == 0 || millis() - spiMS > 1200 ) // display stays on when on backup, but check for data anyway (could glitch)
      {
        if(millis() - spiMS > 1200 && bRestartingDisplay == false) // no data. Maybe disconnected or button press failed
        {
          binPayload.b.noData = 1;
          spiMS = millis();
          checksumData(); // prepare it for transmit

          if(binClientCnt) // send to Windows Goldenchute client(s)
          {
            wsb.binaryAll((uint8_t*)&binPayload, sizeof(binPayload));
          }

#if !(CONFIG_TINYUSB_HID_ENABLED && USE_HID)
          if(bGMFormatSerial) // binary over serial
          {
            Serial.write((uint8_t*)&binPayload, sizeof(binPayload) );
          }
          else // generic text
          {
            Serial.println("NODATA");
          }
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

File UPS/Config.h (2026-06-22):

#ifndef CONFIG_H
#define CONFIG_H

#include <Arduino.h>

#define EESIZE (offsetof(Config, end) - offsetof(Config, size) )

#include <SPIFFS.h> // SPIFFS has no subdirs but takes less code space

#define INTERNAL_FS SPIFFS // No need to upload or format SPIFFS

class Config
{
public:
  Config();
  bool init(void);
  void update(void);

  uint16_t  size = EESIZE;          // if size changes, use defauls
  uint16_t  sum = 0xAAAA;           // if sum is diiferent from memory struct, write
  char      szSSID[32] = ""; // SSID of router (blank for EspTouch)
  char      szSSIDPassword[64] = ""; // password for router
  char      szName[32] = "UPS"; // mDNS and OTA name
  char      szPassword[32] = "password"; // password for web
  uint16_t  ppkw = 160; // 1/10th cents per kwh
  uint32_t  initialDate = 0; // first use or mfg date
  uint16_t  nPercentUsage = 0;
  uint16_t  nCycles = 0;
  uint32_t  lastCycleDate = 0; // last cycle of 100% - should be cycled every 3 months
  uint8_t   ShutoffWattThresh = 50;
  uint8_t   RemainCapLimit = 5;
  uint8_t   WarnCapLimit = 10;
  int8_t    powerLevel = 3;
  bool      bNoBeep = false;
  uint8_t   res[10]; // change the length to force overwrite
  uint8_t   end;

  uint16_t  nDailyWh[31];
  uint16_t  nDailySum;
private:
  uint16_t Fletcher16( uint8_t* data, int count);
};

extern Config cfg;

#endif // PREFS_H

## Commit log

2025-07-11 Found correct connectors
2025-07-15 Added battery level to chart
2025-07-21 Connector problems
2025-07-23 Improving info. XH or XHB option. Corrected resistor value
2025-07-31 Clear button, context menu
2025-08-05 Link to new PCB
2025-08-14 Update for battery levels
2025-08-14 Fixed Incorrect battery levels
    [UPS.ino]
2025-08-16 Battery level 1% resolution
2025-08-23 Rev 2 PCB update
2025-08-23 Changed pin assignments for new design
2025-08-25 Fewer fails for data convert
    [UPS.ino]
2025-08-26 Multi-bin clients, fix for full charge reached
    [UPS.ino]
2025-08-27 Better filter in case display is off
2025-08-28 Error msg if no data
    [UPS.ino]
2025-08-29 Batt level / percent rework
    [UPS.ino]
2025-08-31 Added display restart button
2025-08-31 Change battery bar levels, display restart
2025-09-08 Power usage moved to ESP32
2025-09-08 Added power usage graph
2025-09-08 Used hard coded TZ, added power usage
2025-09-23 Changed bin format, interrupt priority
2025-10-04 Added HID powerdev if ESP32S3
2025-10-05 Wrong link to PCB, removed r2
2025-10-14 Forgot it's not self powered
2025-10-20 Added ESP32-S3
2025-10-30 Added power button
2025-10-30 Fixed health calc, added power button, initialdate setting
    [UPS.ino]
2025-11-02 HID updates were in the wrong place
    [UPS.ino]
2025-11-12 Added delayed power off
2025-11-12 Fixed poweroff value
2025-11-14 Shutoff cancels of not on battery
2025-11-17 Corrected timer under 1 hour
2025-12-13 Fixed cycle add up
    [UPS.ino]
2025-12-15 Fixed potential long button press at start
    [UPS.ino]
2026-01-08 A bit better battery bar reading
2026-01-08 Using raw battery segments
2026-01-08 Changed battery levels to even, bin format, removed peakchargewh
2026-01-11 Timer display and cancel power off
2026-01-11 Support for web shutoff timer, more connect status
2026-02-04 divide by 0 bug
    [UPS.ino]
2026-02-04 Added heatsink
2026-02-05 Update README.md
    New PCB rev
2026-02-20 Missed a variable change, reconnect delay
    [UPS.ino]
2026-02-21 Wrong link to PCB (sorry)
2026-02-25 Lowest TX power to reduce heat
2026-03-22 Changed JST-XH connectors link
2026-03-22 TX power level control
2026-05-31 Adjusted widths and relative websocket path
    Updated styling and script elements in the HTML structure. Modified WebSocket initialization and power level display.
2026-06-22 Added silent/beeping option when on battery.
    Added pin definitions, added new configuration option, and modified several logic conditions for better functionality.
2026-06-22 Revise alert text and power off settings in README
    Updated alert description and clarified power off behavior.
2026-09-10 Update component list in README.md
    Removed unnecessary V2016B heatsink note and added r5 board components.
2026-09-11 Typo: BSS138, not BSS136
    Updated the component list for the r5 board to replace BSS136 with BSS138 MOSFETs.
2026-09-11 Update view and wire widths in eagle.epf
2026-09-11 Add new package and wire connections in pasthru.brd
    [passthru.brd]
2026-09-11 Add PIN HEADER package and connections
    [passthru.sch]
2026-09-13 Added battery option
2026-09-15 Added another SSR for the DPST switch
2026-09-15 Added another SSR for the DPST switch
    Updated attributes and wire connections in UPS.brd.
    [UPS.brd]
2026-09-15 Revise r5 board details in README
    Updated r5 board specifications to include an SSR and additional components. Added notes on button functionality and testing status.
2026-09-17 Rotated btn connector for more room
    [UPS.brd]
2026-09-17 Rotated btn connector for more room
    Updated various parameters including view, wire widths, pad drills, and miter style.
2026-09-17 Update display logic and add power state handling
2026-09-17 Split code for UPS/BMS SSR control
2026-09-24 Power on from webpage when powered off
2026-09-24 Add power on from webpage or external device when power is restored
    Added clarification to the power case and improved logic for toggling power state.
2026-11-11 COM port didn't close when switching to Websocket

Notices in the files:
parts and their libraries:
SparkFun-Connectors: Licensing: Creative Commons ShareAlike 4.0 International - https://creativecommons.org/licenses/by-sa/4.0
